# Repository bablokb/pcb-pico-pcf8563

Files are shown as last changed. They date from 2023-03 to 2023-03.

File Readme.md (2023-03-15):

PCB Pico PCF8563
================

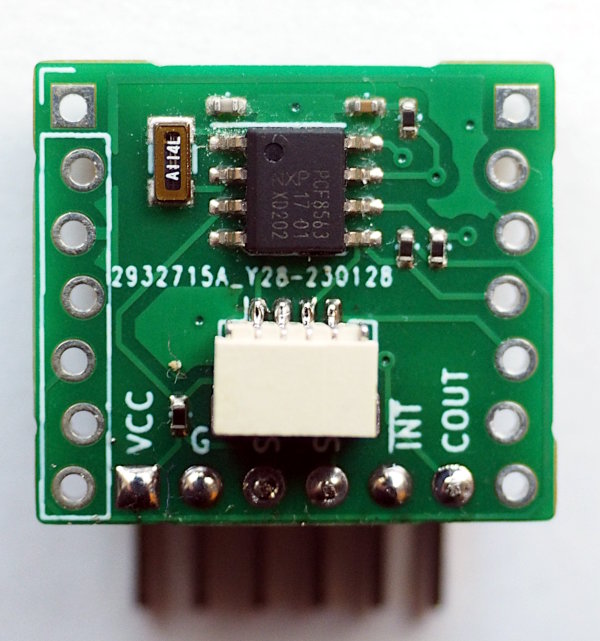
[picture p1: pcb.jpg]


This is a simple breakout with the PCF8563 RTC. It will fit underneath the Pico. It uses
a solderless layout for the Pico-connectors and should hold by itself (but
this is highly dependent on e.g. your pins). As always, this is for prototyping,
you should solder the connectors for permanent projects and best results.

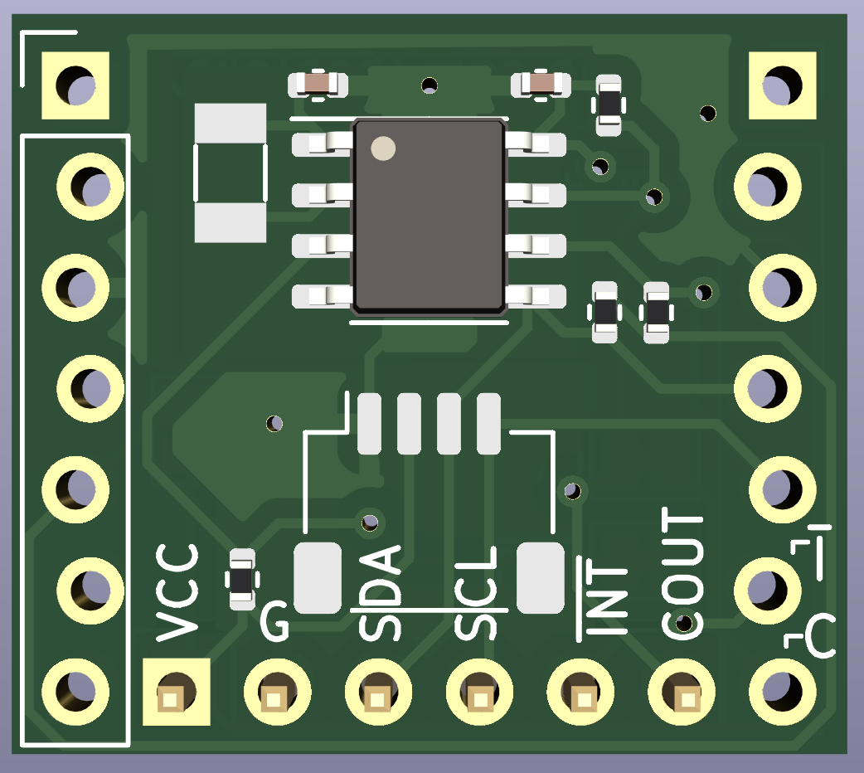
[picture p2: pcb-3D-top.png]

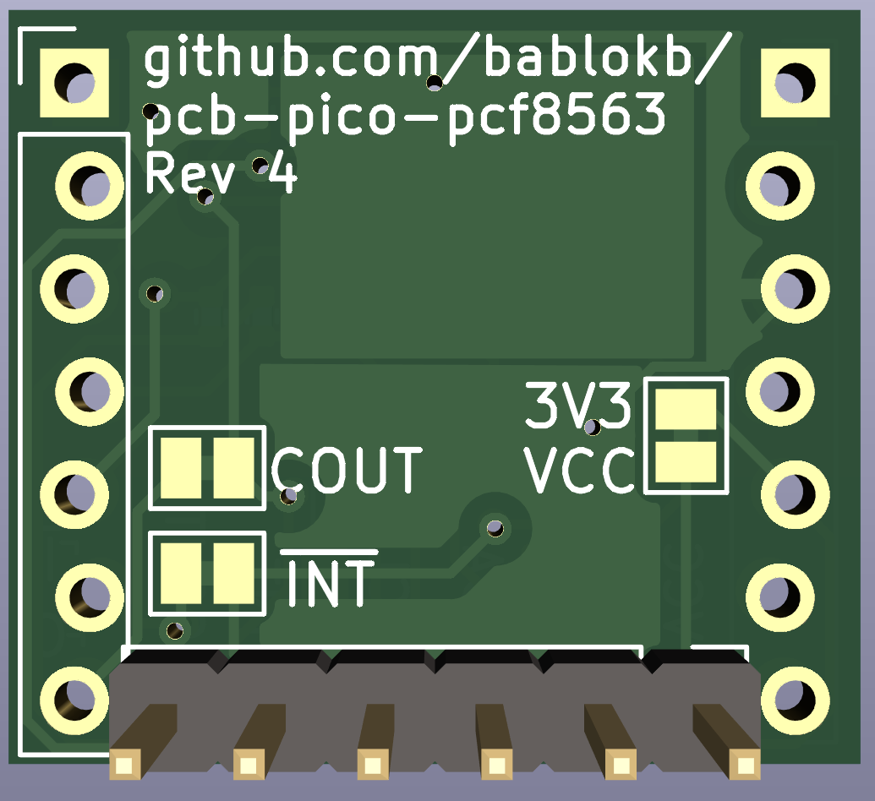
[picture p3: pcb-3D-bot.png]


Hardware
--------

Ready to use production-files for JLCPCB are in the directory `production_files`.

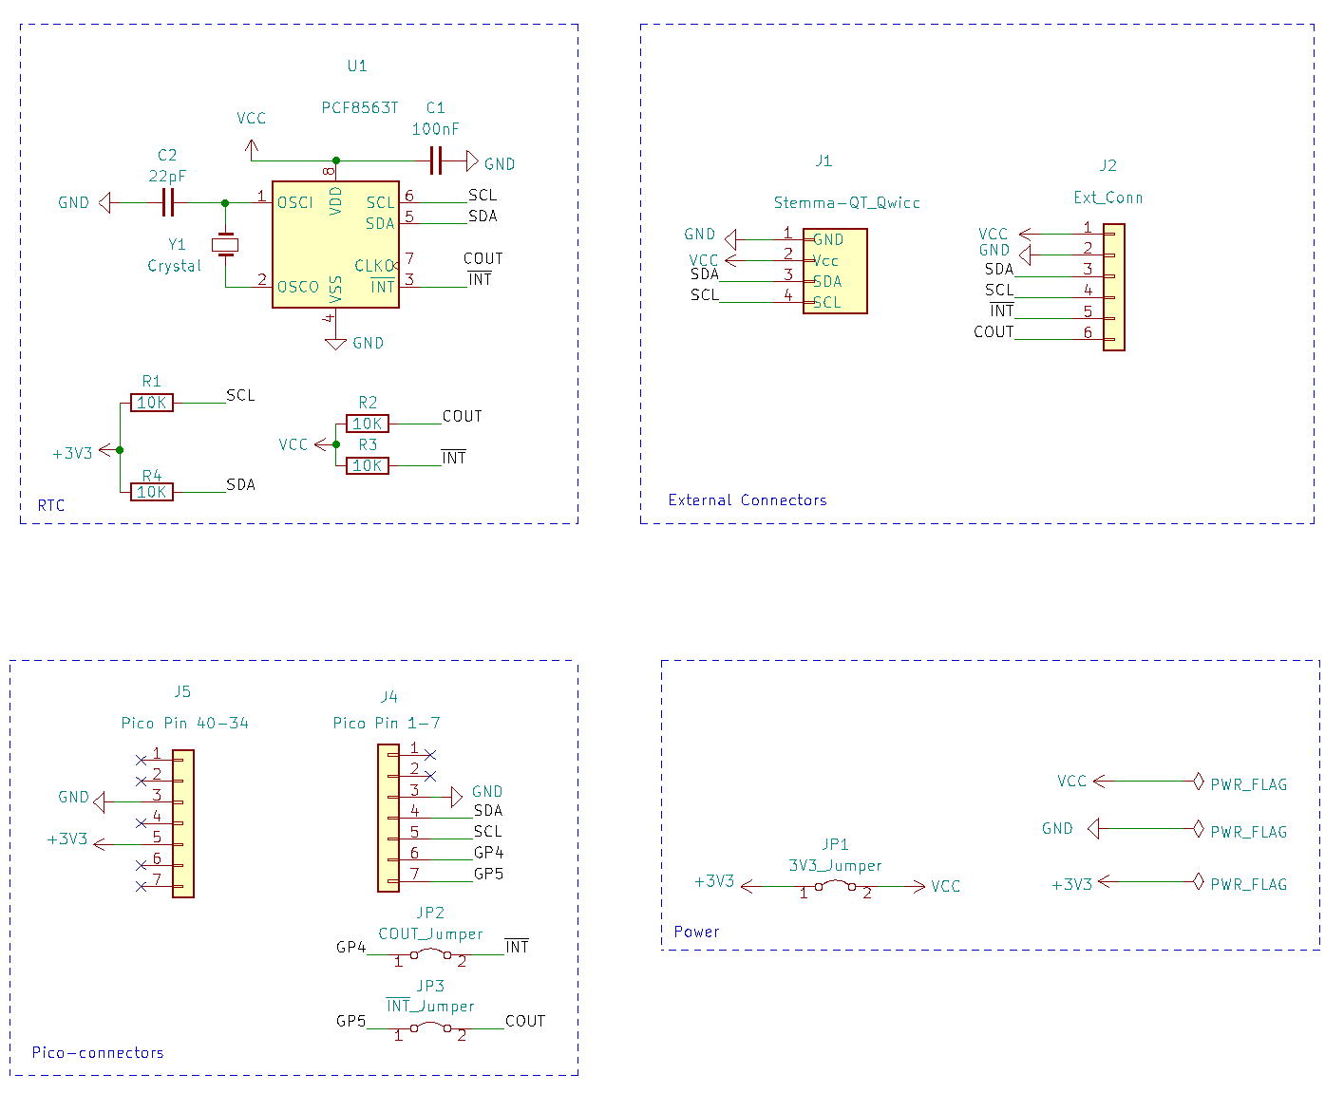
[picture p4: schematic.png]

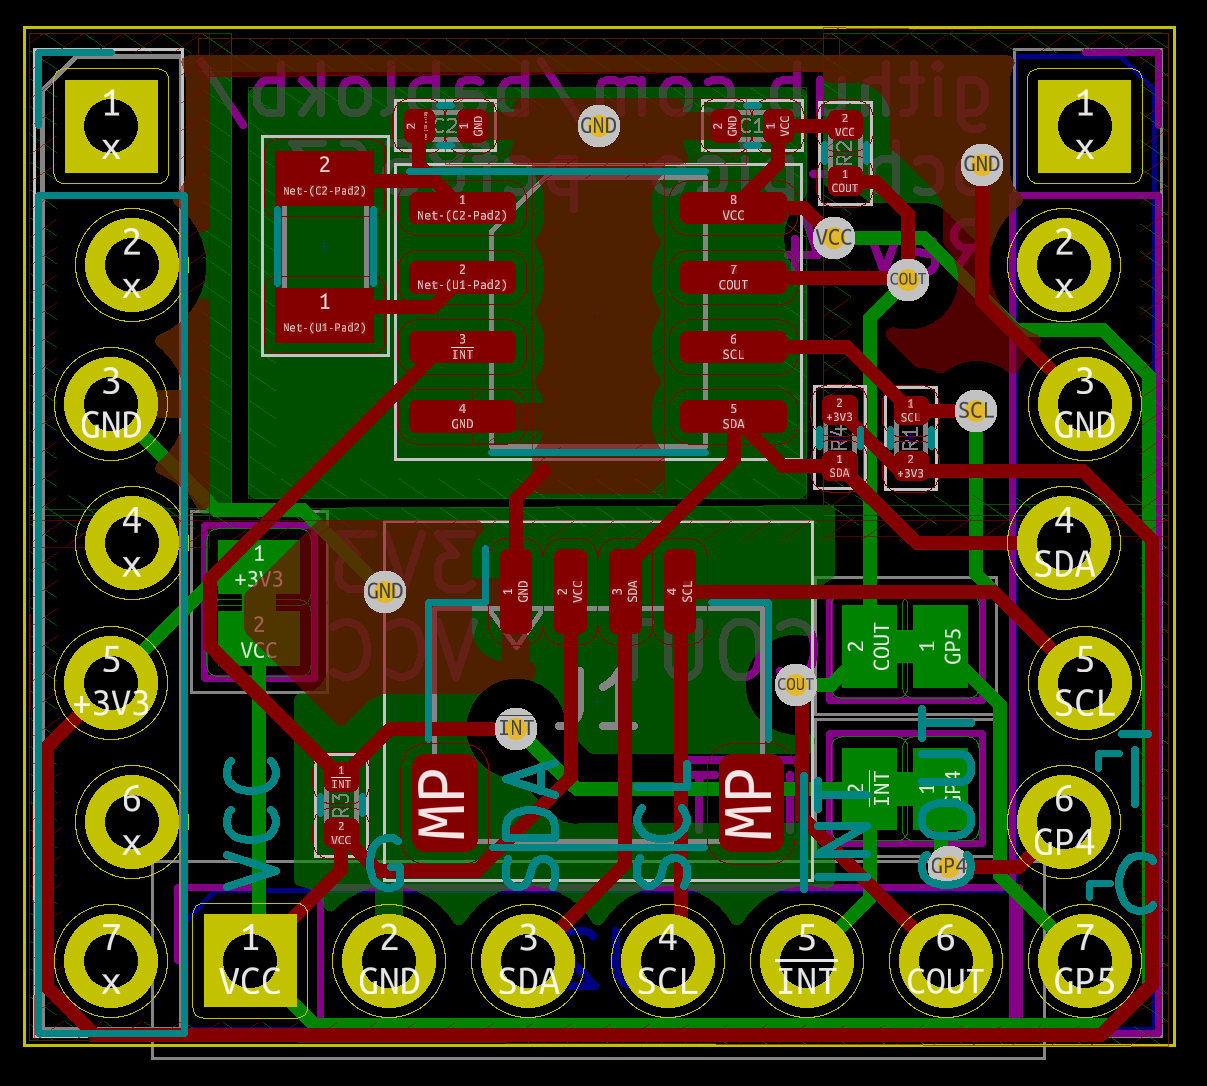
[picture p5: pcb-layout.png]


Special use Jumpers
-------------------

There are three jumpers on the back for special use cases. You can cut the
trace between the jumper marked '3V3 VCC'. The RTC is then only powered by
one of the external connectors (pins or Stemma/Qt) and keeps on running
even if the Pico is shutdown.

The I2C pullups are hard-wired to 3V3, so even when powering the RTC
from an external source, you must still connect the 3V3-pin of the Pico
to the breakout.

If the external voltage is higher than 3V3 (e.g. from a LiPo), you should
also cut the traces labeled COUT and INT to protect the Pico.

License
-------

[![CC BY-SA 4.0][cc-by-sa-shield]][cc-by-sa]

This work is licensed under a
[Creative Commons Attribution-ShareAlike 4.0 International
License][cc-by-sa].

[][cc-by-sa]

[cc-by-sa]: http://creativecommons.org/licenses/by-sa/4.0/
[cc-by-sa-image]: https://licensebuttons.net/l/by-sa/4.0/88x31.png
[cc-by-sa-shield]:
https://img.shields.io/badge/License-CC%20BY--SA%204.0-lightgrey.svg

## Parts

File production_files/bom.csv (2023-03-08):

Comment | Designator | Footprint | LCSC
100nF | C1 | C_0402_1005Metric | C1525
22pF | C2 | C_0402_1005Metric | C1555
10K | R1,R2,R3,R4 | R_0402_1005Metric | C25744
Crystal | Y1 | Crystal_SMD_3215-2Pin_3.2x1.5mm | C32346
PCF8563T | U1 | SOIC-8_3.9x4.9mm_P1.27mm | C7440

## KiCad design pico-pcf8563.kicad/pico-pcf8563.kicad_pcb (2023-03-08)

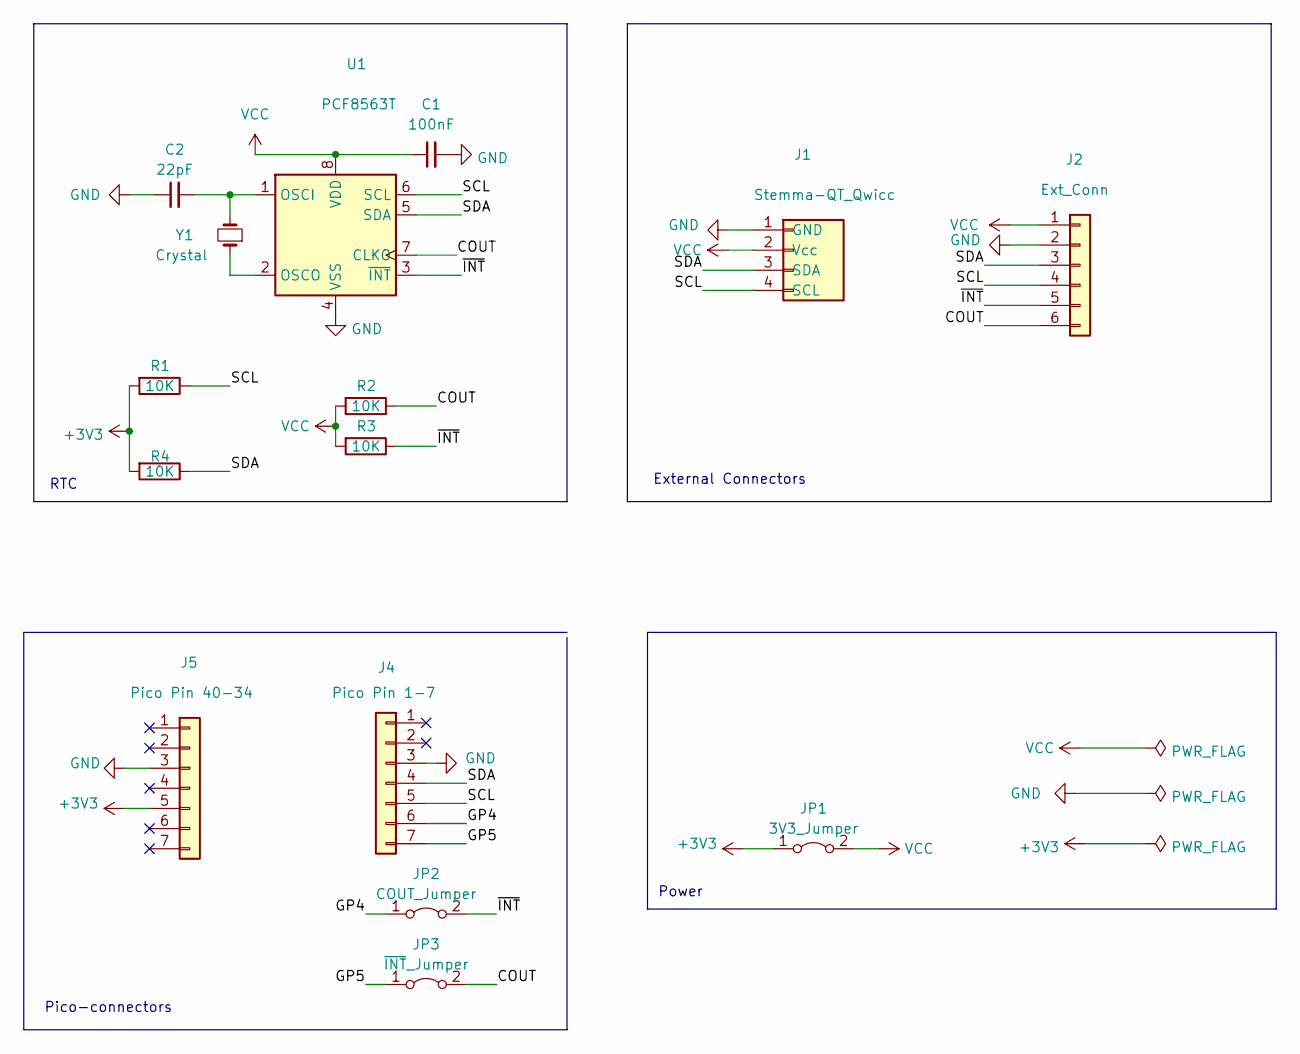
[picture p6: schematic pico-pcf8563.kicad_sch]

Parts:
C1: 100nF; C_0402_1005Metric; LCSC C1525
C2: 22pF; C_0402_1005Metric; LCSC C1555
J1: Stemma-QT_Qwicc; JST_SH_SM04B-SRSS-TB_1x04-1MP_P1.00mm_Horizontal
J2: Ext_Conn; PinHeader_1x06_P2.54mm_Vertical
J4: Pico Pin 1-7; Connector_1x7_no_solder
J5: Pico Pin 40-34; Connector_1x7_no_solder
JP1: 3V3_Jumper; SolderJumper-2_P1.3mm_Bridged_Pad1.0x1.5mm
JP2: COUT_Jumper; SolderJumper-2_P1.3mm_Bridged_Pad1.0x1.5mm
JP3: ~{INT}_Jumper; SolderJumper-2_P1.3mm_Bridged_Pad1.0x1.5mm
R1, R2, R3, R4: 10K; R_0402_1005Metric; LCSC C25744
U1: PCF8563T; SOIC-8_3.9x4.9mm_P1.27mm; LCSC C7440
Y1: Crystal; Crystal_SMD_3215-2Pin_3.2x1.5mm; LCSC C32346

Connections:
+3V3: J5.5, JP1.1 (A), R1.2, R4.2
/COUT: J2.6, JP3.2 (B), R2.1, U1.7 (CLKO)
/GP4: J4.6, JP2.1 (A)
/GP5: J4.7, JP3.1 (A)
/SCL: J1.4 (SCL), J2.4, J4.5, R1.1, U1.6 (SCL)
/SDA: J1.3 (SDA), J2.3, J4.4, R4.1, U1.5 (SDA)
/~INT: J2.5, JP2.2 (B), R3.1, U1.3 (~INT)
GND: C1.2, C2.1, J1.1 (GND), J2.2, J4.3, J5.3, U1.4 (VSS)
unnamed: C2.2, U1.1 (OSCI), Y1.2
unnamed: U1.2 (OSCO), Y1.1
VCC: C1.1, J1.2 (Vcc), J2.1, JP1.2 (B), R2.2, R3.2, U1.8 (VDD)

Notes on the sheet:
External Connectors
Power
Pico-connectors
RTC

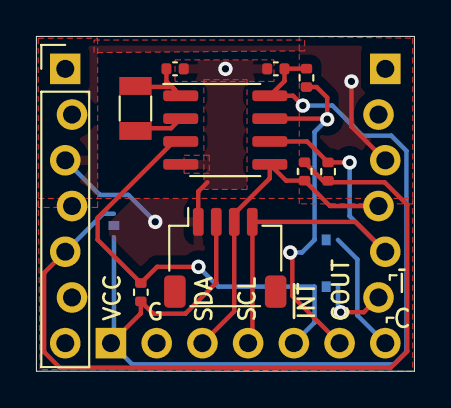
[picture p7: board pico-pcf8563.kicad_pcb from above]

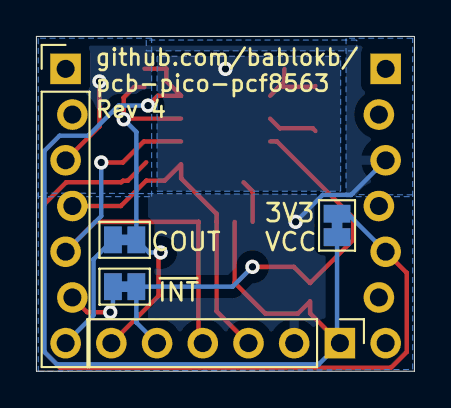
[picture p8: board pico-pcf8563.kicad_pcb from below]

Board: 2 copper layers, 21.0 x 18.6 mm, 15 parts (5 on the bottom side), 11 nets.

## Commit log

2023-01-27 Rev 3
    [pico-pcf8563.kicad_pcb, pico-pcf8563.kicad_sch]
2023-02-17 updated pcb from schematic for Rev3
    [pico-pcf8563.kicad_pcb]
2023-03-08 Rev 4: swapped INT/CLKOUT. The latter is now on GP5
    [bom.csv, pico-pcf8563.kicad_pcb, pico-pcf8563.kicad_sch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]
